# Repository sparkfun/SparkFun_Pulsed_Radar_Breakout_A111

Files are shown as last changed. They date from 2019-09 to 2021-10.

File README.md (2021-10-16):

SparkFun Pulsed Radar Breakout - A111
========================================

SparkFun A111 Pulsed Radar (https://www.sparkfun.com/products/16826)

[*SparkFun A111 Pulsed Radar (SEN-16826)*](https://www.sparkfun.com/products/16826)

Does your project require high-precision, cutting-edge distance measurement? Or maybe speed-, motion-, or gesture-sensing? We’re not talking about simple ultrasonic, or even infrared, sensors here, but 60GHz radar! Well say hello to our tiny, pulsed-radar friend: the Acconeer A111.

The A111 is a single-chip solution for pulsed coherent radar (PCR). It comes complete with integrated antennae and an SPI interface capable of clock speeds of up to 50MHz. The A111’s primary use case is distance-sensing, but it also supports applications in gesture-, motion-, material-, and speed-detection. It can see objects at distances of up to two meters.

Our breakout board for the A111 includes a 1.8V regulator, voltage-level translation between 1.8V and 5V, and, of course, it breaks out all pins of the pulsed radar sensor to both 0.1-inch and Raspberry Pi-friendly headers.

The breakout board is primarily **designed to interface directly with a Raspberry Pi** – Acconeer’s SDK currently only supports ARMv7’s (e.g. a Pi) and ARM Cortex-M4’s. Check out our <a href="https://learn.sparkfun.com/tutorials/getting-started-with-the-a111-pulsed-radar-sensor">Getting Started with the A111 Pulsed Radar Sensor tutorial</a>, which explains how to use the sensor with a Raspberry Pi.

SparkFun labored with love to create this board. Feel like supporting open source hardware? 
Buy a [breakout board](https://www.sparkfun.com/products/16826) from SparkFun!

Repository Contents
-------------------

* **/Documents** - Datasheets
* **/Hardware** - Eagle design files (.brd, .sch)
* **/Production** - Production panel files (.brd)

Documentation
-------------------
* Acconeer
  * **[Developer](https://developer.acconeer.com/)** - SW Download, datasheet, user guide, FAQ
* **[Acconeer Example Code](https://github.com/acconeer)**
* **[Example Code](https://github.com/sparkfun/SparkFun_Pulsed_Radar_A111_Example_Code)** - Archived repo that used to hold the SparkFun example code for the Pulsed Radar Breakout. Make sure to head over to Acconeer's website to download the latest! 
* **[Getting Started Guide](https://learn.sparkfun.com/tutorials/getting-started-with-the-a111-pulsed-radar-sensor)** - Basic hookup guide.

Product Versions
----------------
* [SEN-16826](https://www.sparkfun.com/products/16826) - v1.1
* [SEN-15577](https://www.sparkfun.com/products/15577) - v1.0

Version History
---------------
- v1.1
- [v1.0](https://github.com/sparkfun/SparkFun_Pulsed_Radar_Breakout_A111/releases/tag/v1.0) - initial release

License Information
-------------------

This product is _**open source**_! 

If you have any questions or concerns on licensing, please contact technical support on our [SparkFun forums](https://forum.sparkfun.com/viewforum.php?f=152).

Please use, reuse, and modify these files as you see fit. Please maintain attribution to SparkFun Electronics and release any derivative under the same license.

Distributed as-is; no warranty is given.

- Your friends at SparkFun.

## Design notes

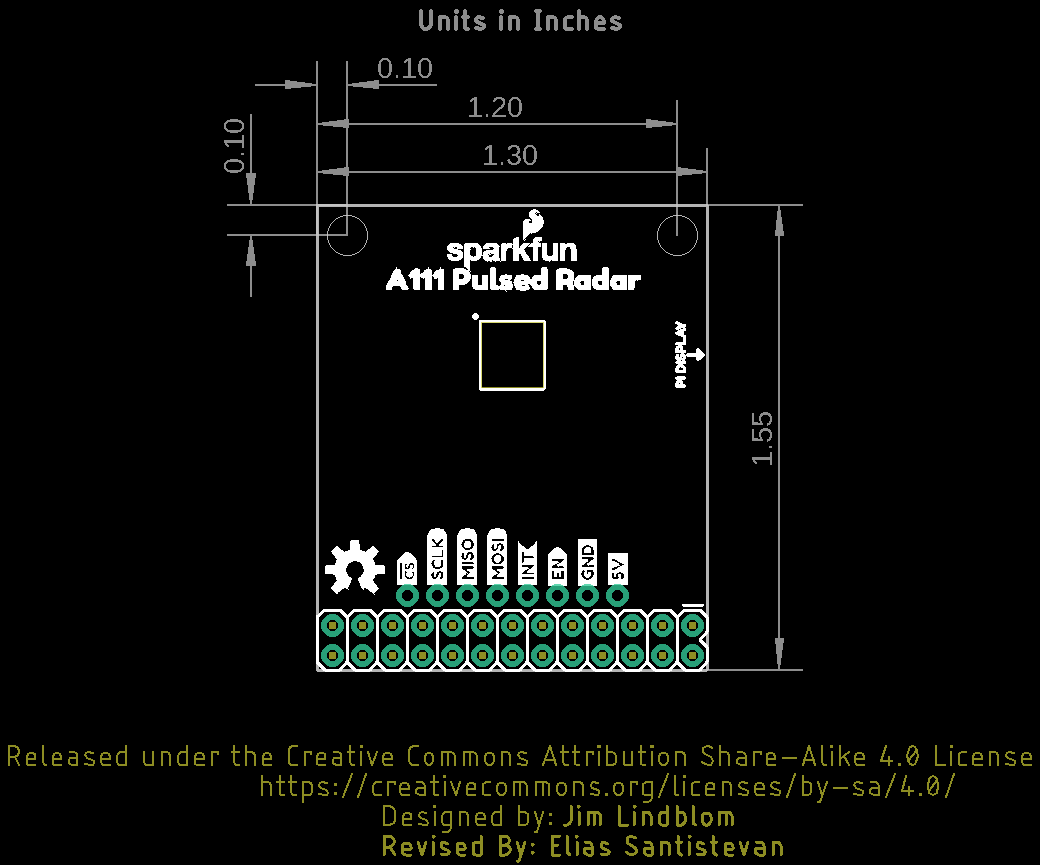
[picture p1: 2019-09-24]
Documentation/SparkFun_A111_Pulsed_Radar_Sensor_Board_Dimensions.png

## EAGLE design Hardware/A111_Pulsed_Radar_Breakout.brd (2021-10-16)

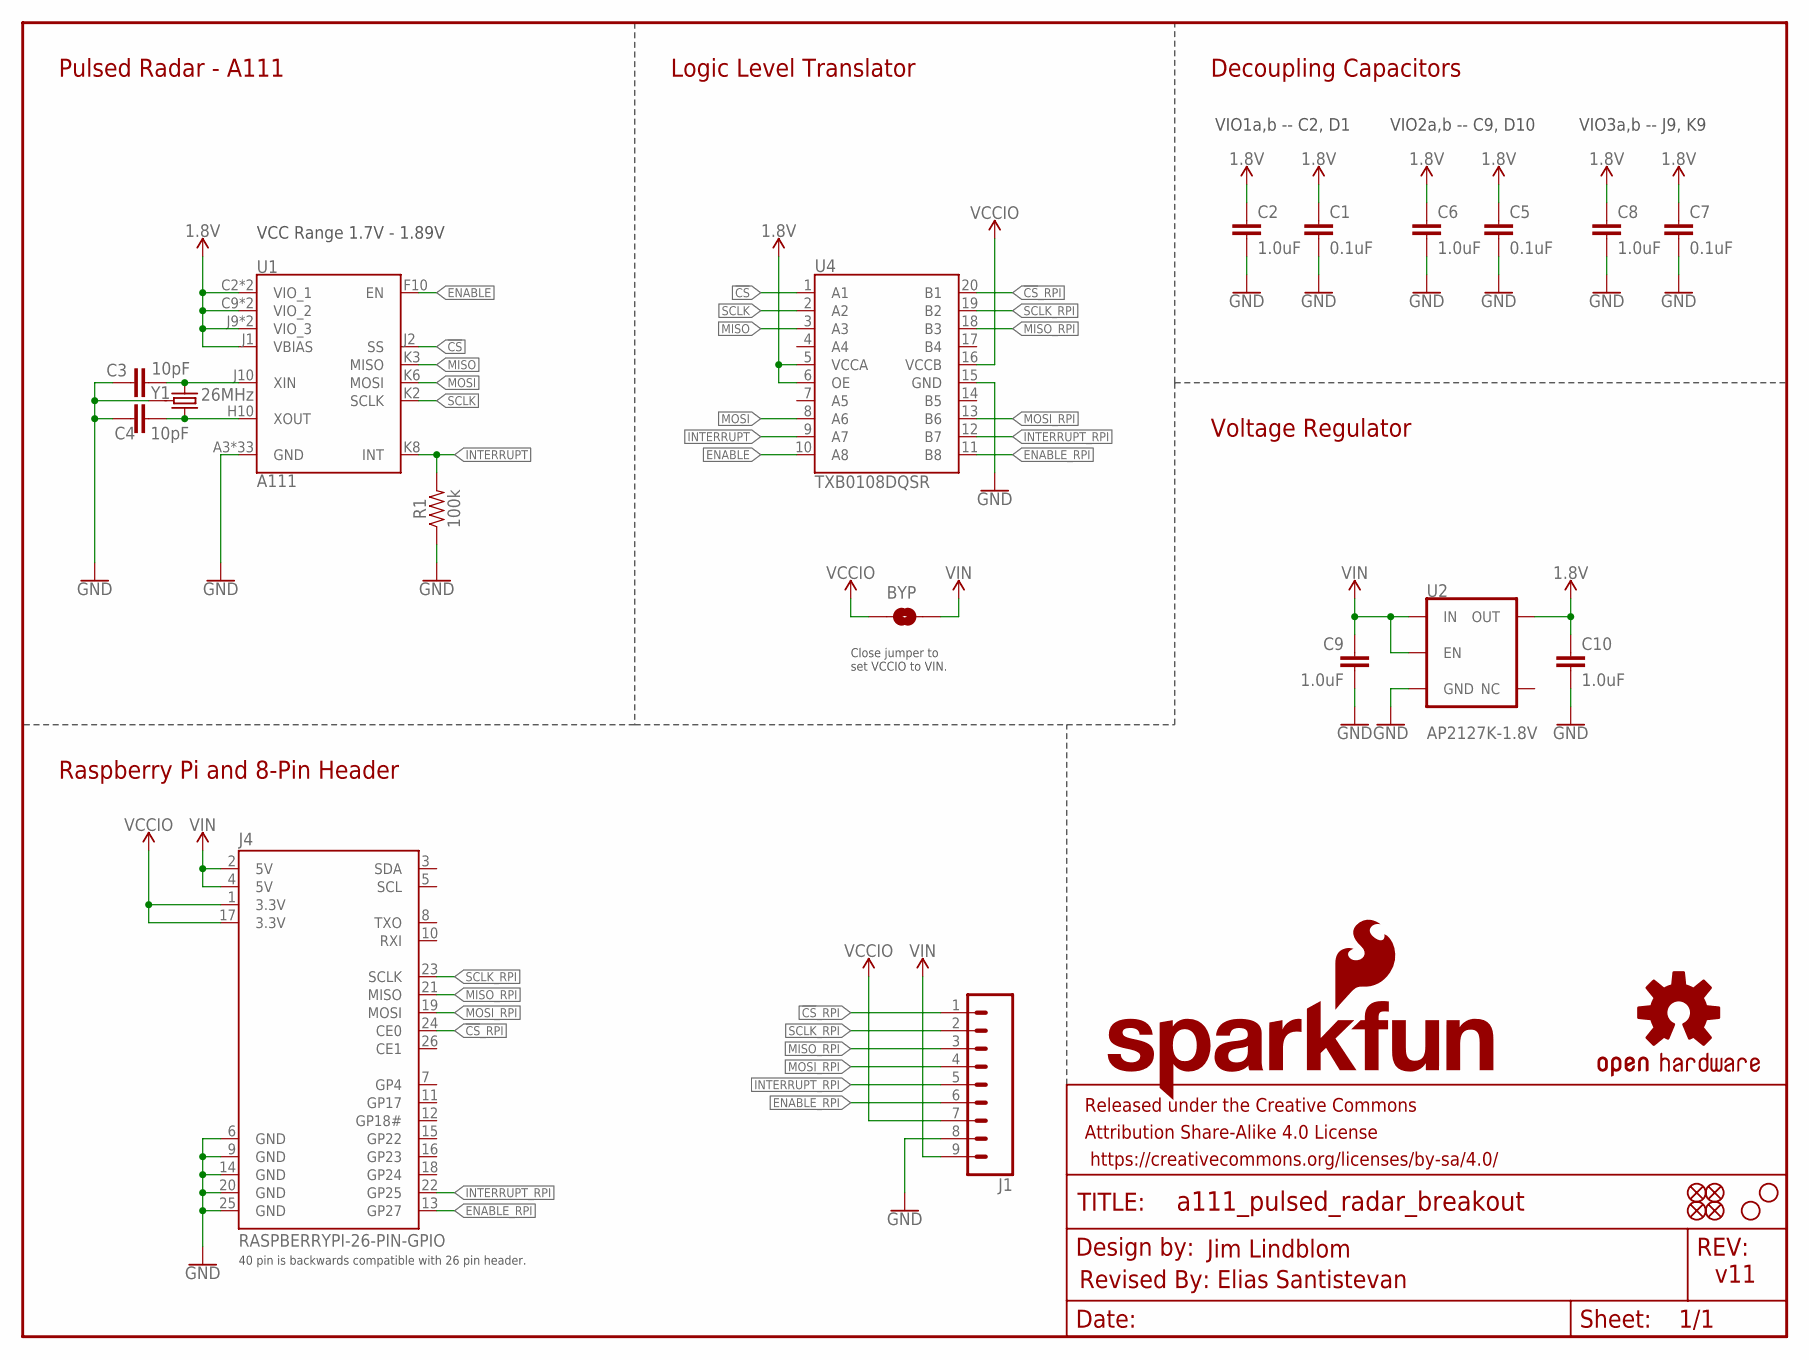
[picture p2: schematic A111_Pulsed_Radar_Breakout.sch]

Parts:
BYP: JUMPER-SMT_2_NO_SILK; SMT-JUMPER_2_NO_SILK
C1, C5, C7: 0.1uF; 0603
C2, C6, C8, C9, C10: 1.0uF; 0603
C3, C4: 10pF; 0603
FD1, FD2, FD3, FD4: FIDUCIALUFIDUCIAL; FIDUCIAL-MICRO
FRAME1: FRAME-LETTER; CREATIVE_COMMONS
H1, H2: STAND-OFF
J1: CONN_09NO_SILK; 1X09_NO_SILK
J4: RASPBERRYPI-26-PIN-GPIO; 2X13
LOGO1: SFE_LOGO_NAME_FLAME.1_INCH; SFE_LOGO_NAME_FLAME_.1
LOGO2: OSHW-LOGOS; OSHW-LOGO-S
R1: 100k; 0603
U1: A111
U2: AP2127K-1.8V; SOT23-5
U4: TXB0108DQSR; UFDFN-20
Y1: 26MHz; CRYSTAL-SMD-3.2X2.5MM

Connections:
1.8V: C1.1, C2.1, C5.1, C6.1, C7.1, C8.1, C10.1, U1.C2 (VIO_1), U1.C9 (VIO_2), U1.D1 (VIO_1), U1.D10 (VIO_2), U1.J1 (VBIAS), U1.J9 (VIO_3), U1.K9 (VIO_3), U2.5 (OUT), U4.5 (VCCA), U4.6 (OE)
!CS!: U1.J2 (SS), U4.1 (A1)
!CS!_RPI: J1.1, J4.24 (CE0), U4.20 (B1)
ENABLE: U1.F10 (EN), U4.10 (A8)
ENABLE_RPI: J1.6, J4.13 (GP27), U4.11 (B8)
GND: C1.2, C2.2, C3.2, C4.1, C5.2, C6.2, C7.2, C8.2, C9.2, C10.2, J1.8, J4.6 (GND), J4.9 (GND), J4.14 (GND), J4.20 (GND), J4.25 (GND), R1.1, U1.A3 (GND), U1.A4 (GND), U1.A5 (GND), U1.A6 (GND), U1.A7 (GND), U1.A8 (GND), U1.A9 (GND), U1.B2 (GND), U1.B9 (GND), U1.B10 (GND), U1.C1 (GND), U1.C10 (GND), U1.D2 (GND), U1.D9 (GND), U1.E1 (GND), U1.E2 (GND), U1.E9 (GND), U1.E10 (GND), U1.F1 (GND), U1.F2 (GND), U1.F9 (GND), U1.G1 (GND), U1.G10 (GND), U1.H1 (GND), U1.H2 (GND), U1.H9 (GND), U1.J3 (GND), U1.J5 (GND), U1.J6 (GND), U1.J8 (GND), U1.K4 (GND), U1.K5 (GND), U1.K7 (GND), U2.2 (GND), U4.15 (GND), Y1.2 (GND), Y1.4 (GND)
INTERRUPT: R1.2, U1.K8 (INT), U4.9 (A7)
INTERRUPT_RPI: J1.5, J4.22 (GP25), U4.12 (B7)
MISO: U1.K3 (MISO), U4.3 (A3)
MISO_RPI: J1.3, J4.21 (MISO), U4.18 (B3)
MOSI: U1.K6 (MOSI), U4.8 (A6)
MOSI_RPI: J1.4, J4.19 (MOSI), U4.13 (B6)
unnamed: C3.1, U1.J10 (XIN), Y1.1
unnamed: C4.2, U1.H10 (XOUT), Y1.3 (2)
SCLK: U1.K2 (SCLK), U4.2 (A2)
SCLK_RPI: J1.2, J4.23 (SCLK), U4.19 (B2)
VCCIO: BYP.1, J1.7, J4.1 (3.3V), J4.17 (3.3V), U4.16 (VCCB)
VIN: BYP.2, C9.1, J1.9, J4.2 (5V), J4.4 (5V), U2.1 (IN), U2.3 (EN)

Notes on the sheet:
VIO1a,b -- C2, D1
VIO2a,b -- C9, D10
VIO3a,b -- J9, K9
Jim Lindblom
Revised By: Elias Santistevan
v11
Pulsed Radar - A111
Logic Level Translator
Decoupling Capacitors
Raspberry Pi and 8-Pin Header
Voltage Regulator
40 pin is backwards compatible with 26 pin header.
VCC Range 1.7V - 1.89V
Close jumper to set VCCIO to VIN.

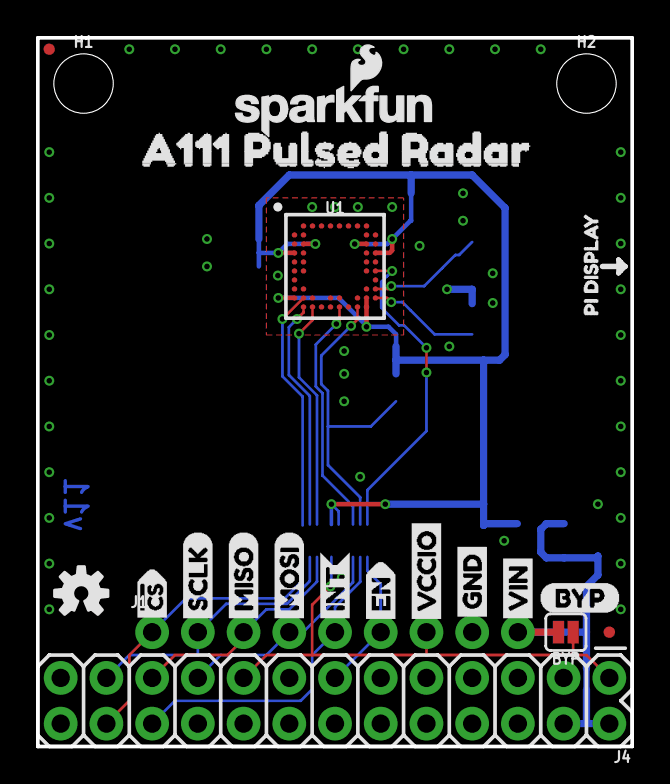
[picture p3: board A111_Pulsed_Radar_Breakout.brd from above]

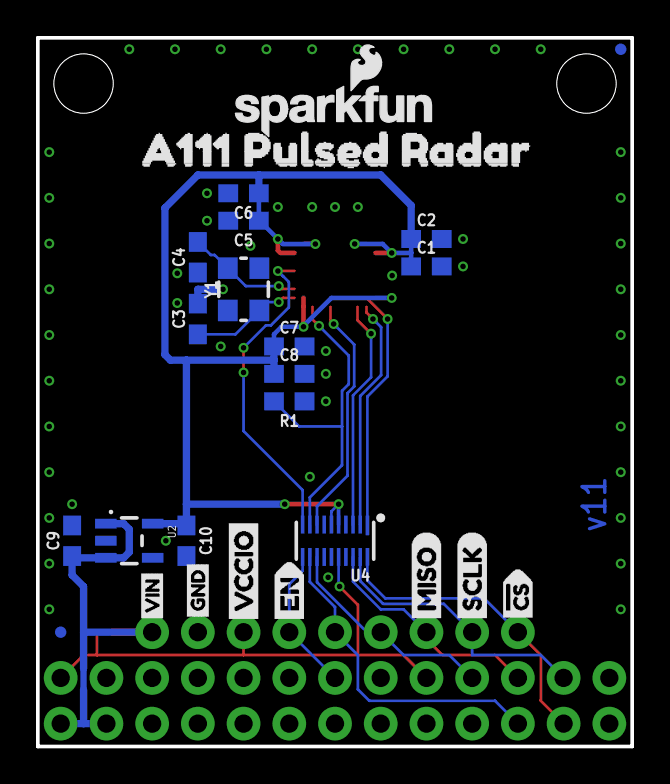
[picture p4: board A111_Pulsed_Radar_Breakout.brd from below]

Board: 2 copper layers, 33.0 x 39.4 mm, 48 parts (25 on the bottom side), 18 nets.

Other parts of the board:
LOGO3: SFE_LOGO_NAME_FLAME.1_INCH; SFE_LOGO_NAME_FLAME_.1
U$1, U$9: A111_PULSED_RADAR9
U$2, U$10: SCLK3
U$3, U$11: MISO4
U$4: MOSI5
U$5: INT8
U$6, U$18: EN9
U$7: GND0
U$8: BYP
U$12: PI_DISPLAY9
U$13, U$17: #CS9
U$16: VIN0
U$19, U$20: VCCIO1
U$21: GND6
U$22: VIN5

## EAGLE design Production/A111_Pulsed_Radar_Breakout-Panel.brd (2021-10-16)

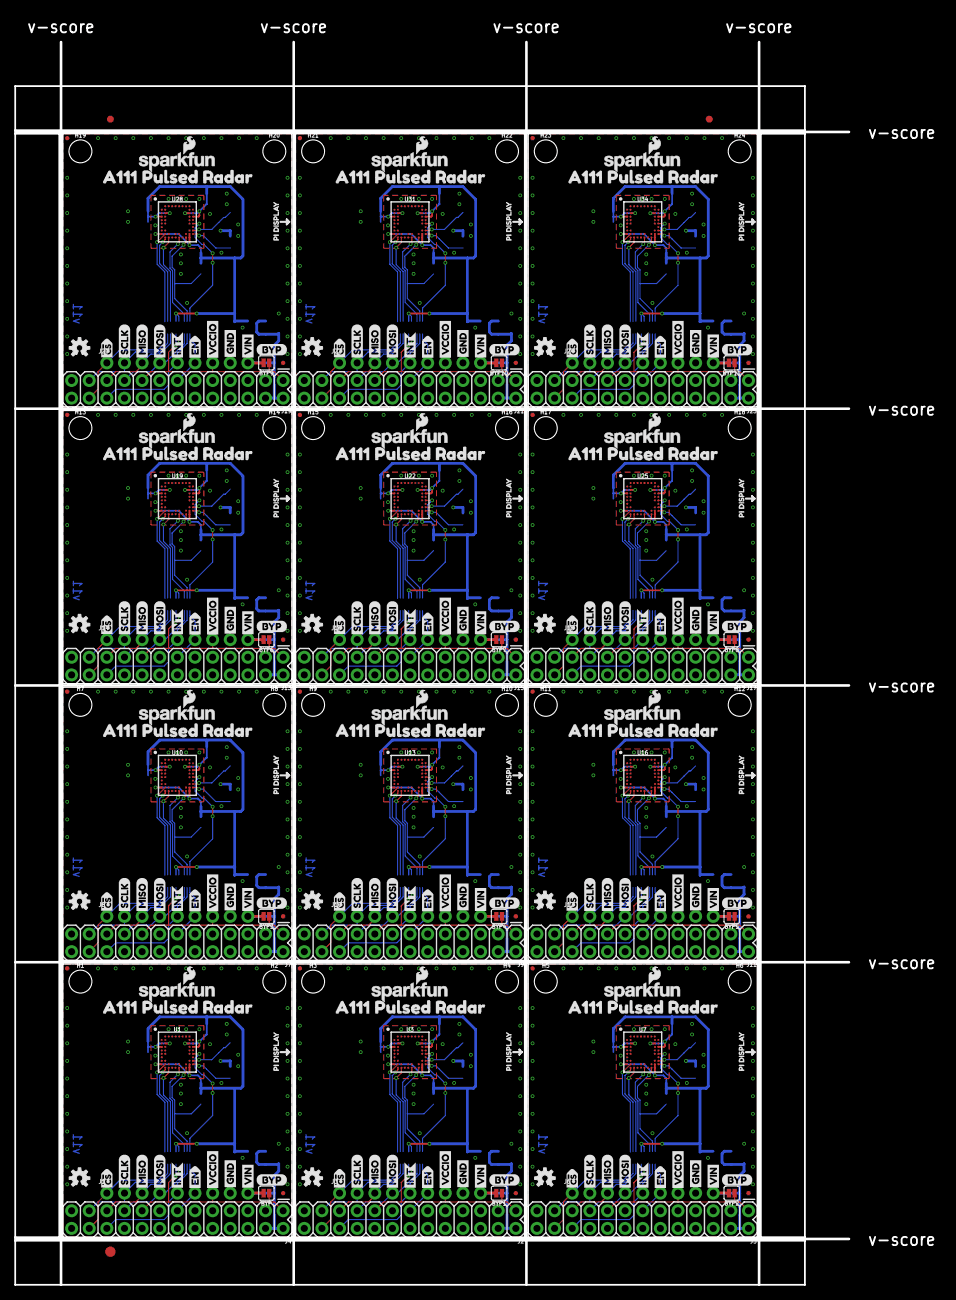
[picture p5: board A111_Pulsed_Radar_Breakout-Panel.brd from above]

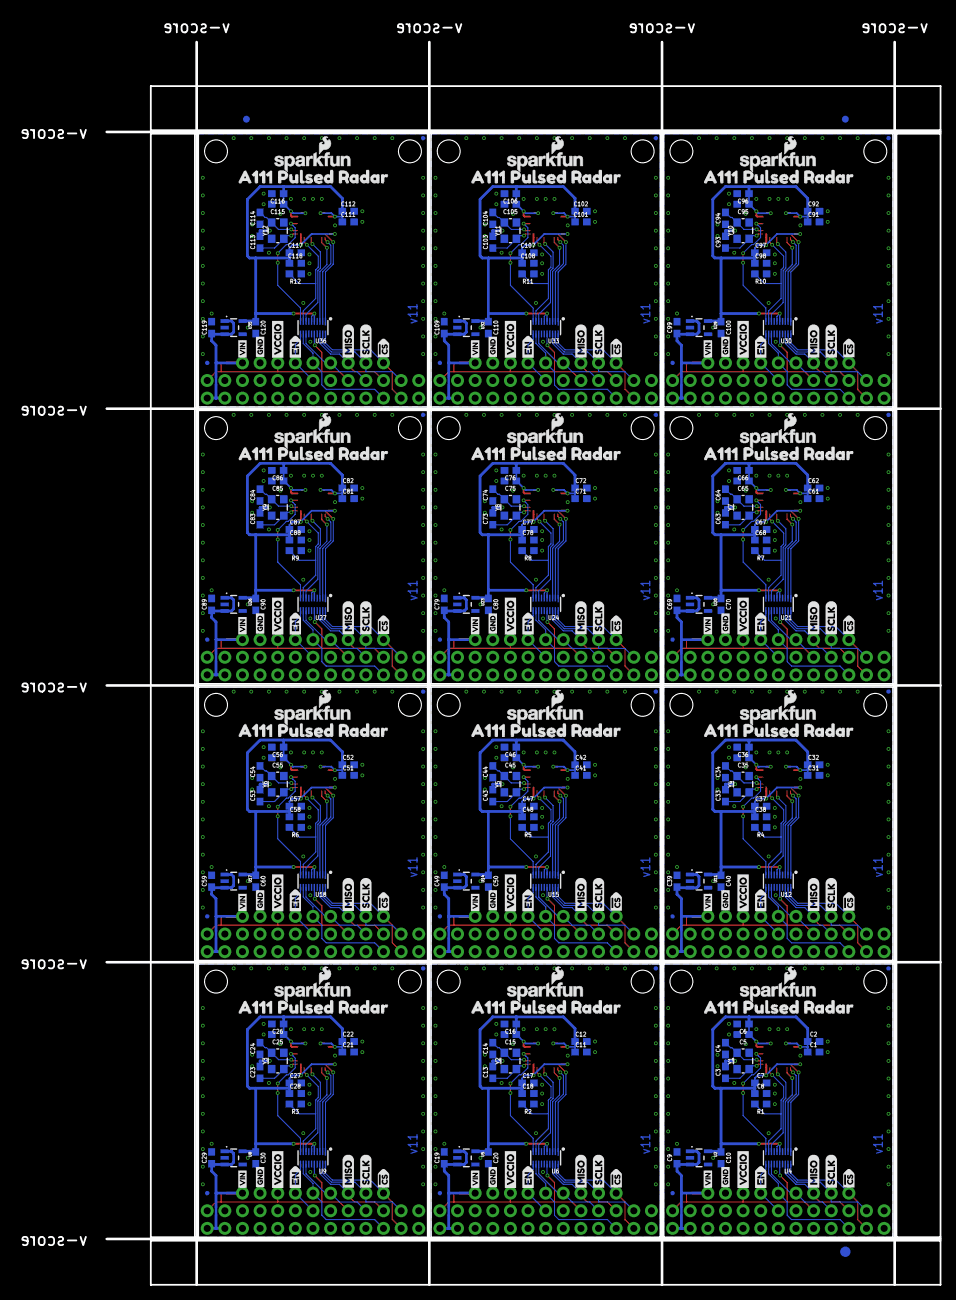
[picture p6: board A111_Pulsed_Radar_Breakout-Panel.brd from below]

Board: 2 copper layers, 120.1 x 179.1 mm, 570 parts (303 on the bottom side), 216 nets.

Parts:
BYP, BYP1, BYP2, BYP3, BYP4, BYP5, BYP6, BYP7, BYP8, BYP9, BYP10, BYP11: JUMPER-SMT_2_NO_SILK; SMT-JUMPER_2_NO_SILK
C1, C5, C7, C11, C15, C17, C21, C25, C27, C31, C35, C37, C41, C45, C47, C51, C55, C57, C61, C65, C67, C71, C75, C77, C81, C85, C87, C91, C95, C97, C101, C105, C107, C111, C115, C117: 0.1uF; 0603
C2, C6, C8, C9, C10, C12, C16, C18, C19, C20, C22, C26, C28, C29, C30, C32, C36, C38, C39, C40, C42, C46, C48, C49, C50, C52, C56, C58, C59, C60, C62, C66, C68, C69, C70, C72, C76, C78, C79, C80, C82, C86, C88, C89, C90, C92, C96, C98, C99, C100, C102, C106, C108, C109, C110, C112, C116, C118, C119, C120: 1.0uF; 0603
C3, C4, C13, C14, C23, C24, C33, C34, C43, C44, C53, C54, C63, C64, C73, C74, C83, C84, C93, C94, C103, C104, C113, C114: 10pF; 0603
E$1, E$2, E$3, E$4: FIDUCIAL-1X2
E$5, E$6: FIDUCIAL-1.5X3
FD1, FD2, FD3, FD4, FD5, FD6, FD7, FD8, FD9, FD10, FD11, FD12, FD13, FD14, FD15, FD16, FD17, FD18, FD19, FD20, FD21, FD22, FD23, FD24, FD25, FD26, FD27, FD28, FD29, FD30, FD31, FD32, FD33, FD34, FD35, FD36, FD37, FD38, FD39, FD40, FD41, FD42, FD43, FD44, FD45, FD46, FD47, FD48: FIDUCIALUFIDUCIAL; FIDUCIAL-MICRO
H1, H2, H3, H4, H5, H6, H7, H8, H9, H10, H11, H12, H13, H14, H15, H16, H17, H18, H19, H20, H21, H22, H23, H24: STAND-OFF
J1, J3, J6, J8, J10, J12, J14, J16, J18, J20, J22, J24: 1X09_NO_SILK
J2, J4, J5, J7, J9, J11, J13, J15, J17, J19, J21, J23: RASPBERRYPI-26-PIN-GPIO; 2X13
LOGO1, LOGO3, LOGO5, LOGO6, LOGO8, LOGO9, LOGO11, LOGO12, LOGO14, LOGO15, LOGO17, LOGO18, LOGO20, LOGO21, LOGO23, LOGO24, LOGO26, LOGO27, LOGO29, LOGO30, LOGO32, LOGO33, LOGO35, LOGO36: SFE_LOGO_NAME_FLAME.1_INCH; SFE_LOGO_NAME_FLAME_.1
LOGO2, LOGO4, LOGO7, LOGO10, LOGO13, LOGO16, LOGO19, LOGO22, LOGO25, LOGO28, LOGO31, LOGO34: OSHW-LOGOS; OSHW-LOGO-S
R1, R2, R3, R4, R5, R6, R7, R8, R9, R10, R11, R12: 100k; 0603
U1, U3, U7, U10, U13, U16, U19, U22, U25, U28, U31, U34: A111
U2, U5, U8, U11, U14, U17, U20, U23, U26, U29, U32, U35: AP2127K-1.8V; SOT23-5
U4, U6, U9, U12, U15, U18, U21, U24, U27, U30, U33, U36: TXB0108DQSR; UFDFN-20
U$1, U$9, U$29, U$30, U$49, U$50, U$69, U$70, U$89, U$90, U$109, U$110, U$129, U$130, U$149, U$150, U$169, U$170, U$189, U$190, U$209, U$210, U$229, U$230: A111_PULSED_RADAR9
U$2, U$10, U$14, U$26, U$41, U$46, U$61, U$66, U$81, U$86, U$101, U$106, U$121, U$126, U$141, U$146, U$161, U$166, U$181, U$186, U$201, U$206, U$221, U$226: SCLK3
U$3, U$11, U$15, U$27, U$42, U$47, U$62, U$67, U$82, U$87, U$102, U$107, U$122, U$127, U$142, U$147, U$162, U$167, U$182, U$187, U$202, U$207, U$222, U$227: MISO4
U$4, U$23, U$43, U$63, U$83, U$103, U$123, U$143, U$163, U$183, U$203, U$223: MOSI5
U$5, U$24, U$44, U$64, U$84, U$104, U$124, U$144, U$164, U$184, U$204, U$224: INT8
U$6, U$18, U$33, U$34, U$53, U$54, U$73, U$74, U$93, U$94, U$113, U$114, U$133, U$134, U$153, U$154, U$173, U$174, U$193, U$194, U$213, U$214, U$233, U$234: EN9
U$7, U$25, U$45, U$65, U$85, U$105, U$125, U$145, U$165, U$185, U$205, U$225: GND0
U$8, U$35, U$55, U$75, U$95, U$115, U$135, U$155, U$175, U$195, U$215, U$235: BYP
U$12, U$31, U$51, U$71, U$91, U$111, U$131, U$151, U$171, U$191, U$211, U$231: PI_DISPLAY9
U$13, U$17, U$28, U$32, U$48, U$52, U$68, U$72, U$88, U$92, U$108, U$112, U$128, U$132, U$148, U$152, U$168, U$172, U$188, U$192, U$208, U$212, U$228, U$232: #CS9
U$16, U$36, U$56, U$76, U$96, U$116, U$136, U$156, U$176, U$196, U$216, U$236: VIN0
U$19, U$20, U$37, U$38, U$57, U$58, U$77, U$78, U$97, U$98, U$117, U$118, U$137, U$138, U$157, U$158, U$177, U$178, U$197, U$198, U$217, U$218, U$237, U$238: VCCIO1
U$21, U$40, U$60, U$80, U$100, U$120, U$140, U$160, U$180, U$200, U$220, U$240: GND6
U$22, U$39, U$59, U$79, U$99, U$119, U$139, U$159, U$179, U$199, U$219, U$239: VIN5
Y1, Y2, Y3, Y4, Y5, Y6, Y7, Y8, Y9, Y10, Y11, Y12: 26MHz; CRYSTAL-SMD-3.2X2.5MM

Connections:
1.8V: C1.1, C2.1, C5.1, C6.1, C7.1, C8.1, C10.1, U1.C2, U1.C9, U1.D1, U1.D10, U1.J1, U1.J9, U1.K9, U2.5, U4.5, U4.6
1.8V1: C11.1, C12.1, C15.1, C16.1, C17.1, C18.1, C20.1, U3.C2, U3.C9, U3.D1, U3.D10, U3.J1, U3.J9, U3.K9, U5.5, U6.5, U6.6
1.8V2: C21.1, C22.1, C25.1, C26.1, C27.1, C28.1, C30.1, U7.C2, U7.C9, U7.D1, U7.D10, U7.J1, U7.J9, U7.K9, U8.5, U9.5, U9.6
1.8V3: C31.1, C32.1, C35.1, C36.1, C37.1, C38.1, C40.1, U10.C2, U10.C9, U10.D1, U10.D10, U10.J1, U10.J9, U10.K9, U11.5, U12.5, U12.6
1.8V4: C41.1, C42.1, C45.1, C46.1, C47.1, C48.1, C50.1, U13.C2, U13.C9, U13.D1, U13.D10, U13.J1, U13.J9, U13.K9, U14.5, U15.5, U15.6
1.8V5: C51.1, C52.1, C55.1, C56.1, C57.1, C58.1, C60.1, U16.C2, U16.C9, U16.D1, U16.D10, U16.J1, U16.J9, U16.K9, U17.5, U18.5, U18.6
1.8V6: C61.1, C62.1, C65.1, C66.1, C67.1, C68.1, C70.1, U19.C2, U19.C9, U19.D1, U19.D10, U19.J1, U19.J9, U19.K9, U20.5, U21.5, U21.6
1.8V7: C71.1, C72.1, C75.1, C76.1, C77.1, C78.1, C80.1, U22.C2, U22.C9, U22.D1, U22.D10, U22.J1, U22.J9, U22.K9, U23.5, U24.5, U24.6
1.8V8: C81.1, C82.1, C85.1, C86.1, C87.1, C88.1, C90.1, U25.C2, U25.C9, U25.D1, U25.D10, U25.J1, U25.J9, U25.K9, U26.5, U27.5, U27.6
1.8V9: C91.1, C92.1, C95.1, C96.1, C97.1, C98.1, C100.1, U28.C2, U28.C9, U28.D1, U28.D10, U28.J1, U28.J9, U28.K9, U29.5, U30.5, U30.6
1.8V10: C101.1, C102.1, C105.1, C106.1, C107.1, C108.1, C110.1, U31.C2, U31.C9, U31.D1, U31.D10, U31.J1, U31.J9, U31.K9, U32.5, U33.5, U33.6
1.8V11: C111.1, C112.1, C115.1, C116.1, C117.1, C118.1, C120.1, U34.C2, U34.C9, U34.D1, U34.D10, U34.J1, U34.J9, U34.K9, U35.5, U36.5, U36.6
!CS!: U1.J2, U4.1
!CS!1: U3.J2, U6.1
!CS!2: U7.J2, U9.1
!CS!3: U10.J2, U12.1
!CS!4: U13.J2, U15.1
!CS!5: U16.J2, U18.1
!CS!6: U19.J2, U21.1
!CS!7: U22.J2, U24.1
!CS!8: U25.J2, U27.1
!CS!9: U28.J2, U30.1
!CS!10: U31.J2, U33.1
!CS!11: U34.J2, U36.1
!CS!_RPI: J1.1, J4.24, U4.20
!CS!_RPI1: J2.24, J3.1, U6.20
!CS!_RPI2: J5.24, J6.1, U9.20
!CS!_RPI3: J7.24, J8.1, U12.20
!CS!_RPI4: J9.24, J10.1, U15.20
!CS!_RPI5: J11.24, J12.1, U18.20
!CS!_RPI6: J13.24, J14.1, U21.20
!CS!_RPI7: J15.24, J16.1, U24.20
!CS!_RPI8: J17.24, J18.1, U27.20
!CS!_RPI9: J19.24, J20.1, U30.20
!CS!_RPI10: J21.24, J22.1, U33.20
!CS!_RPI11: J23.24, J24.1, U36.20
ENABLE: U1.F10, U4.10
ENABLE1: U3.F10, U6.10
ENABLE2: U7.F10, U9.10
ENABLE3: U10.F10, U12.10
ENABLE4: U13.F10, U15.10
ENABLE5: U16.F10, U18.10
ENABLE6: U19.F10, U21.10
ENABLE7: U22.F10, U24.10
ENABLE8: U25.F10, U27.10
ENABLE9: U28.F10, U30.10
ENABLE10: U31.F10, U33.10
ENABLE11: U34.F10, U36.10
ENABLE_RPI: J1.6, J4.13, U4.11
ENABLE_RPI1: J2.13, J3.6, U6.11
ENABLE_RPI2: J5.13, J6.6, U9.11
ENABLE_RPI3: J7.13, J8.6, U12.11
ENABLE_RPI4: J9.13, J10.6, U15.11
ENABLE_RPI5: J11.13, J12.6, U18.11
ENABLE_RPI6: J13.13, J14.6, U21.11
ENABLE_RPI7: J15.13, J16.6, U24.11
ENABLE_RPI8: J17.13, J18.6, U27.11
ENABLE_RPI9: J19.13, J20.6, U30.11
ENABLE_RPI10: J21.13, J22.6, U33.11
ENABLE_RPI11: J23.13, J24.6, U36.11
GND: C1.2, C2.2, C3.2, C4.1, C5.2, C6.2, C7.2, C8.2, C9.2, C10.2, J1.8, J4.6, J4.9, J4.14, J4.20, J4.25, R1.1, U1.A3, U1.A4, U1.A5, U1.A6, U1.A7, U1.A8, U1.A9, U1.B2, U1.B9, U1.B10, U1.C1, U1.C10, U1.D2, U1.D9, U1.E1, U1.E2, U1.E9, U1.E10, U1.F1, U1.F2, U1.F9, U1.G1, U1.G10, U1.H1, U1.H2, U1.H9, U1.J3, U1.J5, U1.J6, U1.J8, U1.K4, U1.K5, U1.K7, U2.2, U4.15, Y1.2, Y1.4
GND1: C11.2, C12.2, C13.2, C14.1, C15.2, C16.2, C17.2, C18.2, C19.2, C20.2, J2.6, J2.9, J2.14, J2.20, J2.25, J3.8, R2.1, U3.A3, U3.A4, U3.A5, U3.A6, U3.A7, U3.A8, U3.A9, U3.B2, U3.B9, U3.B10, U3.C1, U3.C10, U3.D2, U3.D9, U3.E1, U3.E2, U3.E9, U3.E10, U3.F1, U3.F2, U3.F9, U3.G1, U3.G10, U3.H1, U3.H2, U3.H9, U3.J3, U3.J5, U3.J6, U3.J8, U3.K4, U3.K5, U3.K7, U5.2, U6.15, Y2.2, Y2.4
GND2: C21.2, C22.2, C23.2, C24.1, C25.2, C26.2, C27.2, C28.2, C29.2, C30.2, J5.6, J5.9, J5.14, J5.20, J5.25, J6.8, R3.1, U7.A3, U7.A4, U7.A5, U7.A6, U7.A7, U7.A8, U7.A9, U7.B2, U7.B9, U7.B10, U7.C1, U7.C10, U7.D2, U7.D9, U7.E1, U7.E2, U7.E9, U7.E10, U7.F1, U7.F2, U7.F9, U7.G1, U7.G10, U7.H1, U7.H2, U7.H9, U7.J3, U7.J5, U7.J6, U7.J8, U7.K4, U7.K5, U7.K7, U8.2, U9.15, Y3.2, Y3.4
GND3: C31.2, C32.2, C33.2, C34.1, C35.2, C36.2, C37.2, C38.2, C39.2, C40.2, J7.6, J7.9, J7.14, J7.20, J7.25, J8.8, R4.1, U10.A3, U10.A4, U10.A5, U10.A6, U10.A7, U10.A8, U10.A9, U10.B2, U10.B9, U10.B10, U10.C1, U10.C10, U10.D2, U10.D9, U10.E1, U10.E2, U10.E9, U10.E10, U10.F1, U10.F2, U10.F9, U10.G1, U10.G10, U10.H1, U10.H2, U10.H9, U10.J3, U10.J5, U10.J6, U10.J8, U10.K4, U10.K5, U10.K7, U11.2, U12.15, Y4.2, Y4.4
GND4: C41.2, C42.2, C43.2, C44.1, C45.2, C46.2, C47.2, C48.2, C49.2, C50.2, J9.6, J9.9, J9.14, J9.20, J9.25, J10.8, R5.1, U13.A3, U13.A4, U13.A5, U13.A6, U13.A7, U13.A8, U13.A9, U13.B2, U13.B9, U13.B10, U13.C1, U13.C10, U13.D2, U13.D9, U13.E1, U13.E2, U13.E9, U13.E10, U13.F1, U13.F2, U13.F9, U13.G1, U13.G10, U13.H1, U13.H2, U13.H9, U13.J3, U13.J5, U13.J6, U13.J8, U13.K4, U13.K5, U13.K7, U14.2, U15.15, Y5.2, Y5.4
GND5: C51.2, C52.2, C53.2, C54.1, C55.2, C56.2, C57.2, C58.2, C59.2, C60.2, J11.6, J11.9, J11.14, J11.20, J11.25, J12.8, R6.1, U16.A3, U16.A4, U16.A5, U16.A6, U16.A7, U16.A8, U16.A9, U16.B2, U16.B9, U16.B10, U16.C1, U16.C10, U16.D2, U16.D9, U16.E1, U16.E2, U16.E9, U16.E10, U16.F1, U16.F2, U16.F9, U16.G1, U16.G10, U16.H1, U16.H2, U16.H9, U16.J3, U16.J5, U16.J6, U16.J8, U16.K4, U16.K5, U16.K7, U17.2, U18.15, Y6.2, Y6.4
GND6: C61.2, C62.2, C63.2, C64.1, C65.2, C66.2, C67.2, C68.2, C69.2, C70.2, J13.6, J13.9, J13.14, J13.20, J13.25, J14.8, R7.1, U19.A3, U19.A4, U19.A5, U19.A6, U19.A7, U19.A8, U19.A9, U19.B2, U19.B9, U19.B10, U19.C1, U19.C10, U19.D2, U19.D9, U19.E1, U19.E2, U19.E9, U19.E10, U19.F1, U19.F2, U19.F9, U19.G1, U19.G10, U19.H1, U19.H2, U19.H9, U19.J3, U19.J5, U19.J6, U19.J8, U19.K4, U19.K5, U19.K7, U20.2, U21.15, Y7.2, Y7.4
GND7: C71.2, C72.2, C73.2, C74.1, C75.2, C76.2, C77.2, C78.2, C79.2, C80.2, J15.6, J15.9, J15.14, J15.20, J15.25, J16.8, R8.1, U22.A3, U22.A4, U22.A5, U22.A6, U22.A7, U22.A8, U22.A9, U22.B2, U22.B9, U22.B10, U22.C1, U22.C10, U22.D2, U22.D9, U22.E1, U22.E2, U22.E9, U22.E10, U22.F1, U22.F2, U22.F9, U22.G1, U22.G10, U22.H1, U22.H2, U22.H9, U22.J3, U22.J5, U22.J6, U22.J8, U22.K4, U22.K5, U22.K7, U23.2, U24.15, Y8.2, Y8.4
GND8: C81.2, C82.2, C83.2, C84.1, C85.2, C86.2, C87.2, C88.2, C89.2, C90.2, J17.6, J17.9, J17.14, J17.20, J17.25, J18.8, R9.1, U25.A3, U25.A4, U25.A5, U25.A6, U25.A7, U25.A8, U25.A9, U25.B2, U25.B9, U25.B10, U25.C1, U25.C10, U25.D2, U25.D9, U25.E1, U25.E2, U25.E9, U25.E10, U25.F1, U25.F2, U25.F9, U25.G1, U25.G10, U25.H1, U25.H2, U25.H9, U25.J3, U25.J5, U25.J6, U25.J8, U25.K4, U25.K5, U25.K7, U26.2, U27.15, Y9.2, Y9.4
GND9: C91.2, C92.2, C93.2, C94.1, C95.2, C96.2, C97.2, C98.2, C99.2, C100.2, J19.6, J19.9, J19.14, J19.20, J19.25, J20.8, R10.1, U28.A3, U28.A4, U28.A5, U28.A6, U28.A7, U28.A8, U28.A9, U28.B2, U28.B9, U28.B10, U28.C1, U28.C10, U28.D2, U28.D9, U28.E1, U28.E2, U28.E9, U28.E10, U28.F1, U28.F2, U28.F9, U28.G1, U28.G10, U28.H1, U28.H2, U28.H9, U28.J3, U28.J5, U28.J6, U28.J8, U28.K4, U28.K5, U28.K7, U29.2, U30.15, Y10.2, Y10.4
GND10: C101.2, C102.2, C103.2, C104.1, C105.2, C106.2, C107.2, C108.2, C109.2, C110.2, J21.6, J21.9, J21.14, J21.20, J21.25, J22.8, R11.1, U31.A3, U31.A4, U31.A5, U31.A6, U31.A7, U31.A8, U31.A9, U31.B2, U31.B9, U31.B10, U31.C1, U31.C10, U31.D2, U31.D9, U31.E1, U31.E2, U31.E9, U31.E10, U31.F1, U31.F2, U31.F9, U31.G1, U31.G10, U31.H1, U31.H2, U31.H9, U31.J3, U31.J5, U31.J6, U31.J8, U31.K4, U31.K5, U31.K7, U32.2, U33.15, Y11.2, Y11.4
GND11: C111.2, C112.2, C113.2, C114.1, C115.2, C116.2, C117.2, C118.2, C119.2, C120.2, J23.6, J23.9, J23.14, J23.20, J23.25, J24.8, R12.1, U34.A3, U34.A4, U34.A5, U34.A6, U34.A7, U34.A8, U34.A9, U34.B2, U34.B9, U34.B10, U34.C1, U34.C10, U34.D2, U34.D9, U34.E1, U34.E2, U34.E9, U34.E10, U34.F1, U34.F2, U34.F9, U34.G1, U34.G10, U34.H1, U34.H2, U34.H9, U34.J3, U34.J5, U34.J6, U34.J8, U34.K4, U34.K5, U34.K7, U35.2, U36.15, Y12.2, Y12.4
INTERRUPT: R1.2, U1.K8, U4.9
INTERRUPT1: R2.2, U3.K8, U6.9
INTERRUPT2: R3.2, U7.K8, U9.9
INTERRUPT3: R4.2, U10.K8, U12.9
INTERRUPT4: R5.2, U13.K8, U15.9
INTERRUPT5: R6.2, U16.K8, U18.9
INTERRUPT6: R7.2, U19.K8, U21.9
INTERRUPT7: R8.2, U22.K8, U24.9
INTERRUPT8: R9.2, U25.K8, U27.9
INTERRUPT9: R10.2, U28.K8, U30.9
INTERRUPT10: R11.2, U31.K8, U33.9
INTERRUPT11: R12.2, U34.K8, U36.9
INTERRUPT_RPI: J1.5, J4.22, U4.12
INTERRUPT_RPI1: J2.22, J3.5, U6.12
INTERRUPT_RPI2: J5.22, J6.5, U9.12
INTERRUPT_RPI3: J7.22, J8.5, U12.12
INTERRUPT_RPI4: J9.22, J10.5, U15.12
INTERRUPT_RPI5: J11.22, J12.5, U18.12
INTERRUPT_RPI6: J13.22, J14.5, U21.12
INTERRUPT_RPI7: J15.22, J16.5, U24.12
INTERRUPT_RPI8: J17.22, J18.5, U27.12
INTERRUPT_RPI9: J19.22, J20.5, U30.12
INTERRUPT_RPI10: J21.22, J22.5, U33.12
INTERRUPT_RPI11: J23.22, J24.5, U36.12
MISO: U1.K3, U4.3
MISO1: U3.K3, U6.3
MISO2: U7.K3, U9.3
MISO3: U10.K3, U12.3
MISO4: U13.K3, U15.3
MISO5: U16.K3, U18.3
MISO6: U19.K3, U21.3
MISO7: U22.K3, U24.3
MISO8: U25.K3, U27.3
MISO9: U28.K3, U30.3
MISO10: U31.K3, U33.3
MISO11: U34.K3, U36.3
MISO_RPI: J1.3, J4.21, U4.18
MISO_RPI1: J2.21, J3.3, U6.18
MISO_RPI2: J5.21, J6.3, U9.18
MISO_RPI3: J7.21, J8.3, U12.18
MISO_RPI4: J9.21, J10.3, U15.18
MISO_RPI5: J11.21, J12.3, U18.18
MISO_RPI6: J13.21, J14.3, U21.18
MISO_RPI7: J15.21, J16.3, U24.18
MISO_RPI8: J17.21, J18.3, U27.18
MISO_RPI9: J19.21, J20.3, U30.18
MISO_RPI10: J21.21, J22.3, U33.18
MISO_RPI11: J23.21, J24.3, U36.18
MOSI: U1.K6, U4.8
MOSI1: U3.K6, U6.8
MOSI2: U7.K6, U9.8
MOSI3: U10.K6, U12.8
MOSI4: U13.K6, U15.8
MOSI5: U16.K6, U18.8
MOSI6: U19.K6, U21.8
MOSI7: U22.K6, U24.8
MOSI8: U25.K6, U27.8
MOSI9: U28.K6, U30.8
MOSI10: U31.K6, U33.8
MOSI11: U34.K6, U36.8
MOSI_RPI: J1.4, J4.19, U4.13
MOSI_RPI1: J2.19, J3.4, U6.13
MOSI_RPI2: J5.19, J6.4, U9.13
MOSI_RPI3: J7.19, J8.4, U12.13
MOSI_RPI4: J9.19, J10.4, U15.13
MOSI_RPI5: J11.19, J12.4, U18.13
MOSI_RPI6: J13.19, J14.4, U21.13
MOSI_RPI7: J15.19, J16.4, U24.13
MOSI_RPI8: J17.19, J18.4, U27.13
MOSI_RPI9: J19.19, J20.4, U30.13
MOSI_RPI10: J21.19, J22.4, U33.13
MOSI_RPI11: J23.19, J24.4, U36.13
unnamed: C3.1, U1.J10, Y1.1
unnamed: C4.2, U1.H10, Y1.3
unnamed: C13.1, U3.J10, Y2.1
unnamed: C14.2, U3.H10, Y2.3
unnamed: C23.1, U7.J10, Y3.1
unnamed: C24.2, U7.H10, Y3.3
unnamed: C33.1, U10.J10, Y4.1
unnamed: C34.2, U10.H10, Y4.3
unnamed: C43.1, U13.J10, Y5.1
unnamed: C44.2, U13.H10, Y5.3
unnamed: C53.1, U16.J10, Y6.1
unnamed: C54.2, U16.H10, Y6.3
unnamed: C63.1, U19.J10, Y7.1
unnamed: C64.2, U19.H10, Y7.3
unnamed: C73.1, U22.J10, Y8.1
unnamed: C74.2, U22.H10, Y8.3
unnamed: C83.1, U25.J10, Y9.1
unnamed: C84.2, U25.H10, Y9.3
unnamed: C93.1, U28.J10, Y10.1
unnamed: C94.2, U28.H10, Y10.3
unnamed: C103.1, U31.J10, Y11.1
unnamed: C104.2, U31.H10, Y11.3
unnamed: C113.1, U34.J10, Y12.1
unnamed: C114.2, U34.H10, Y12.3
SCLK: U1.K2, U4.2
SCLK1: U3.K2, U6.2
SCLK2: U7.K2, U9.2
SCLK3: U10.K2, U12.2
SCLK4: U13.K2, U15.2
SCLK5: U16.K2, U18.2
SCLK6: U19.K2, U21.2
SCLK7: U22.K2, U24.2
SCLK8: U25.K2, U27.2
SCLK9: U28.K2, U30.2
SCLK10: U31.K2, U33.2
SCLK11: U34.K2, U36.2
SCLK_RPI: J1.2, J4.23, U4.19
SCLK_RPI1: J2.23, J3.2, U6.19
SCLK_RPI2: J5.23, J6.2, U9.19
SCLK_RPI3: J7.23, J8.2, U12.19
SCLK_RPI4: J9.23, J10.2, U15.19
SCLK_RPI5: J11.23, J12.2, U18.19
SCLK_RPI6: J13.23, J14.2, U21.19
SCLK_RPI7: J15.23, J16.2, U24.19
SCLK_RPI8: J17.23, J18.2, U27.19
SCLK_RPI9: J19.23, J20.2, U30.19
SCLK_RPI10: J21.23, J22.2, U33.19
SCLK_RPI11: J23.23, J24.2, U36.19
VCCIO: BYP.1, J1.7, J4.1, J4.17, U4.16
VCCIO1: BYP1.1, J2.1, J2.17, J3.7, U6.16
VCCIO2: BYP2.1, J5.1, J5.17, J6.7, U9.16
VCCIO3: BYP3.1, J7.1, J7.17, J8.7, U12.16
VCCIO4: BYP4.1, J9.1, J9.17, J10.7, U15.16
VCCIO5: BYP5.1, J11.1, J11.17, J12.7, U18.16
VCCIO6: BYP6.1, J13.1, J13.17, J14.7, U21.16
VCCIO7: BYP7.1, J15.1, J15.17, J16.7, U24.16
VCCIO8: BYP8.1, J17.1, J17.17, J18.7, U27.16
VCCIO9: BYP9.1, J19.1, J19.17, J20.7, U30.16
VCCIO10: BYP10.1, J21.1, J21.17, J22.7, U33.16
VCCIO11: BYP11.1, J23.1, J23.17, J24.7, U36.16
VIN: BYP.2, C9.1, J1.9, J4.2, J4.4, U2.1, U2.3
VIN1: BYP1.2, C19.1, J2.2, J2.4, J3.9, U5.1, U5.3
VIN2: BYP2.2, C29.1, J5.2, J5.4, J6.9, U8.1, U8.3
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

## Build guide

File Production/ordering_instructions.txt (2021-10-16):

panel size, 114x166mm
PCB thickness, 1.6mm
number of layers, 2
soldermask color, Red
silkscreen color, White
oz copper, 1oz
finish, HASL lead free
stencils, top+bottom
pcs per panel, 12
min trace width, 0.1524mm / 0.0060in
min drill size, 0.3048mm / 0.0120in

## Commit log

2019-08-05 Adds SparkFun logo to the underside, migrates all parts to SparkFun libraries.
    [A111_Pulsed_Radar_Breakout.brd, A111_Pulsed_Radar_Breakout.sch]
2019-08-05 Updates A111 with SKU
    [A111_Pulsed_Radar_Breakout.brd, A111_Pulsed_Radar_Breakout.sch]
2019-08-06 Replaces SparkFun silk with SparkFun silk with flame, grounds, 1.8V voltage regulator
    [A111_Pulsed_Radar_Breakout.brd, A111_Pulsed_Radar_Breakout.sch]
2019-08-08 Changes DRC to SparkFun Fab Limit
    [A111_Pulsed_Radar_Breakout.brd]
2019-08-08 Adds Production Files
    [A111_Pulsed_Radar_Breakout-Panel.brd]
2019-08-08 Fixes proportional text in schematic
    [A111_Pulsed_Radar_Breakout.sch]
2019-08-08 Updates schematic with VCC range, updates silk on A111 part
    [A111_Pulsed_Radar_Breakout.brd, A111_Pulsed_Radar_Breakout.sch]
2019-08-08 Updates silk once more
    [A111_Pulsed_Radar_Breakout.brd, A111_Pulsed_Radar_Breakout.sch]
2019-08-08 Repanelizes after silk change
    [A111_Pulsed_Radar_Breakout-Panel.brd]
2019-09-24 Board Dimensions
    - Update measures layer
    - Include board dimensions
    [A111_Pulsed_Radar_Breakout.brd]
2019-12-20 Update README.md
    The logic level converter is tied directly to 5V
2020-05-07 Splits power to level translation so that it's at on a separate power bus (3.3V on Rasp Pi)
    [A111_Pulsed_Radar_Breakout.brd, A111_Pulsed_Radar_Breakout.sch]
2020-06-03 Updates the panel
    [A111_Pulsed_Radar_Breakout-Panel.GBL, A111_Pulsed_Radar_Breakout-Panel.GBO, A111_Pulsed_Radar_Breakout-Panel.GBP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]

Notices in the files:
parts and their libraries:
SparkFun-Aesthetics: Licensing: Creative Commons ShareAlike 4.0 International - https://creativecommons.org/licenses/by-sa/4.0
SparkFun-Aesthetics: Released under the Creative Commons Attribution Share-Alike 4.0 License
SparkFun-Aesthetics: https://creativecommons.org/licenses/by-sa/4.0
